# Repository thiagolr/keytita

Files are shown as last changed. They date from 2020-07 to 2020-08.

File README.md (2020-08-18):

KeyTita
========

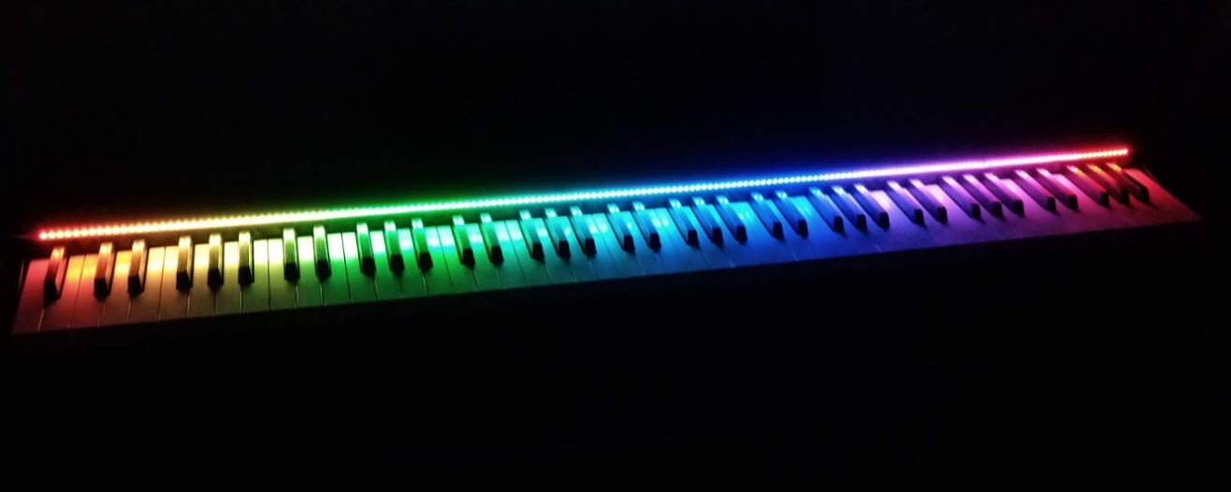
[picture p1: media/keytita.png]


This project allows you to learn a song note by note on the piano, by lighting up appropriate LED lights that correspond to each individual key on the piano.

### Modes

- <b>Learn</b>: the piano will show which note should be played and then it will wait for you
- <b>Listen</b>: the piano will play the song and you will watch which notes it is playing
- <b>Play</b>: play any song and the piano will light up the notes played

### How It Works

The main unit is composed by an Arduino Leonardo and an USB-Host Shield. The piano is connected to the USB-Host Shield and a PC or mobile device running [Synthesia](https://synthesiagame.com/) is connected to the Arduino Leonardo.

[Synthesia](https://synthesiagame.com/) shows any MIDI song as falling notes, then the Arduino Leonardo board receives this information and lights up the appropriate LED. When you press a piano key, this information is sent back to Synthesia.

An android application is available to setup the key colors and effects.

### Materials and Tools

- Arduino Leonardo
- Arduino USB-Host Board
- WS2812B Led Strip (144 led/m)
- 5V Power Supply
- 1000 uF capacitor
- 470 ohm resistor
- 3D Printer

### Electronics

A 1000 uF capacitor was added across the + and – terminals from the power supply to buffer sudden changes in the current drawn by the LED strip. A 470 ohm resistor was added to the LED strip data line to reduce the noise.

### LED Support

A [LED support](https://www.thingiverse.com/thing:4555365) was designed using OpenSCAD in order to hold the LED strip, it is fully parametric and can be easily adjusted to other pianos or keyboards.

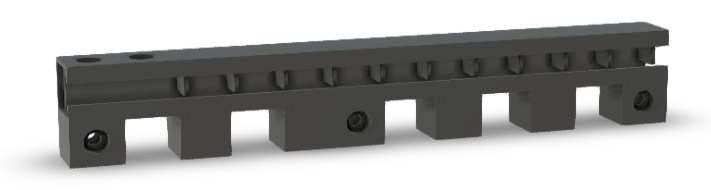
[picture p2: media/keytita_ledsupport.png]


### Box Case

The [box case](https://github.com/zygmuntw/3D-Printed-Case-for-Arduino) holding the Arduino Leonardo and the USB-Host Shield was based on the work of [Zygmunt Wojcik](https://github.com/zygmuntw). It was [modified](https://www.thingiverse.com/thing:4555365) to fit the USB-Host Shield connected above the Arduino Leonardo board.

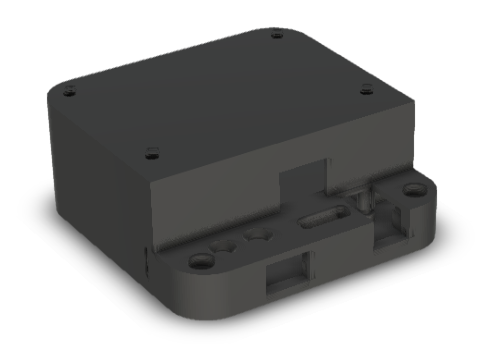
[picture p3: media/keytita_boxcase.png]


### Android Application

The application allows you to select the key colors and the brightness. There are some predefined colors and sequences/effects, but it is also possible to set custom colors.

The application is automatically launched and connected, every time you plug the USB cable between your phone/tablet and the Arduino Leonardo.

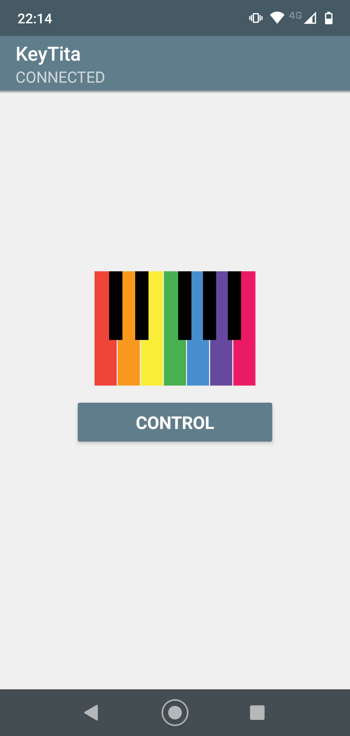
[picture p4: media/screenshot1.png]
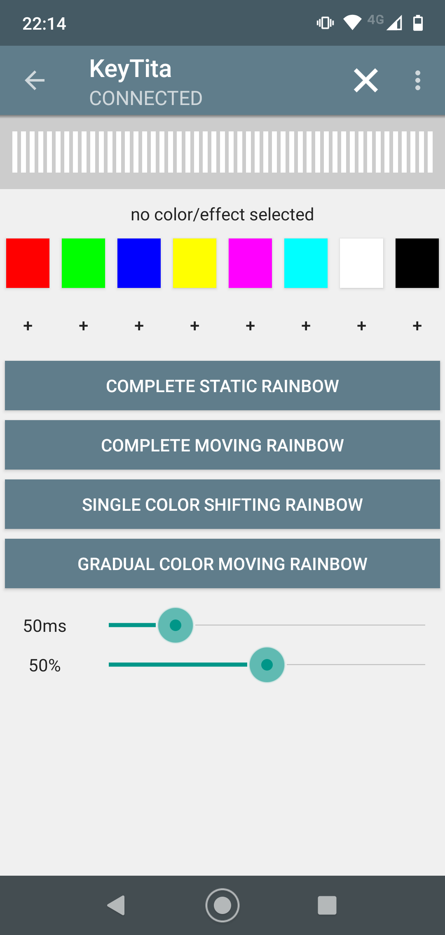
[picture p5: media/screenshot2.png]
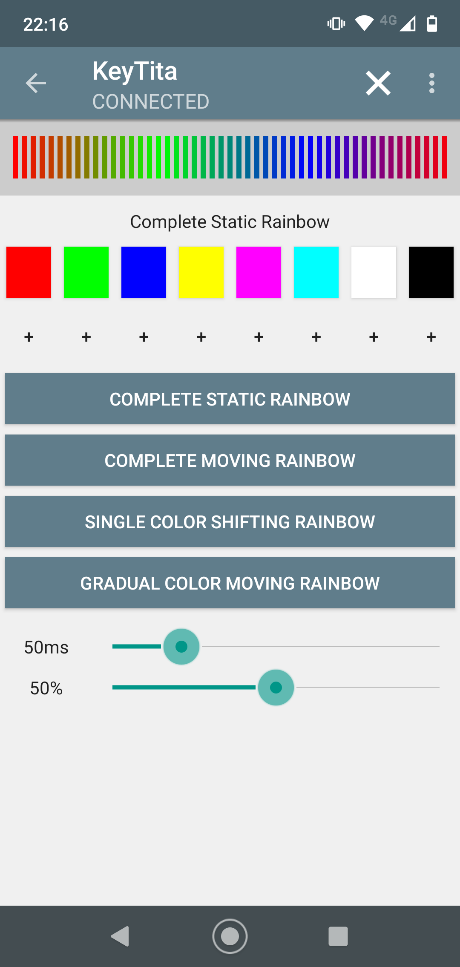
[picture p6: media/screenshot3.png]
&nbsp;&nbsp;&nbsp;&nbsp;&nbsp;&nbsp;&nbsp;&nbsp;

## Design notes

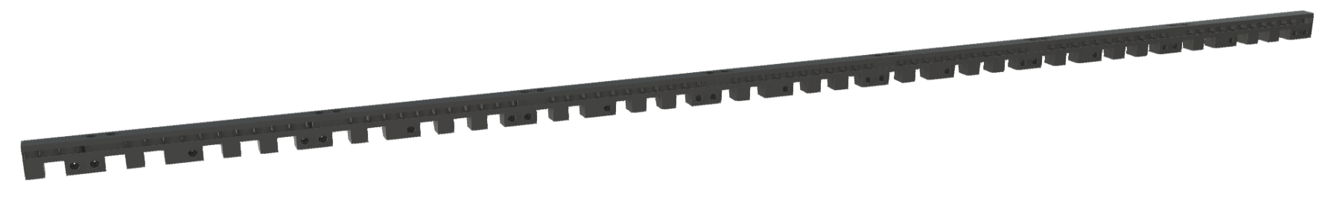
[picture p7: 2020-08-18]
media/keytita_ledsupport_full.png

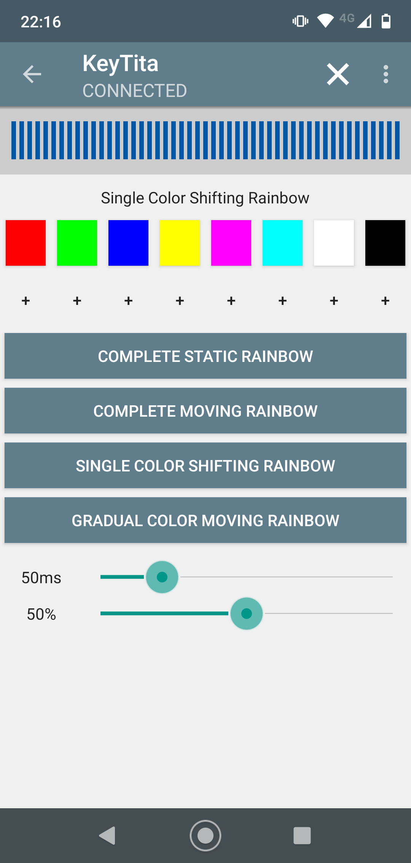
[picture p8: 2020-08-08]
media/screenshot5.png

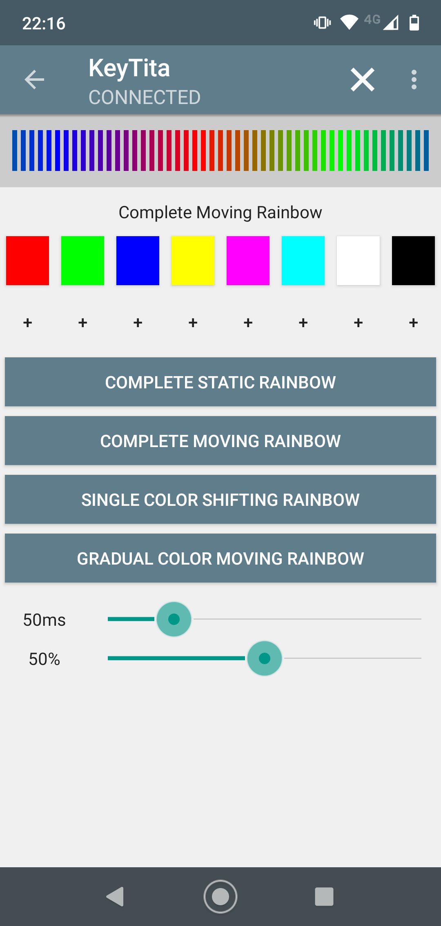
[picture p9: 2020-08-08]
media/screenshot4.png

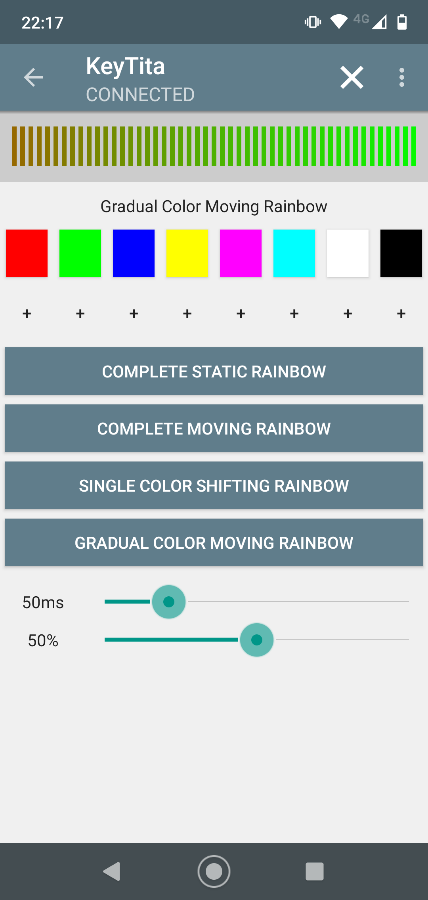
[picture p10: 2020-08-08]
media/screenshot6.png

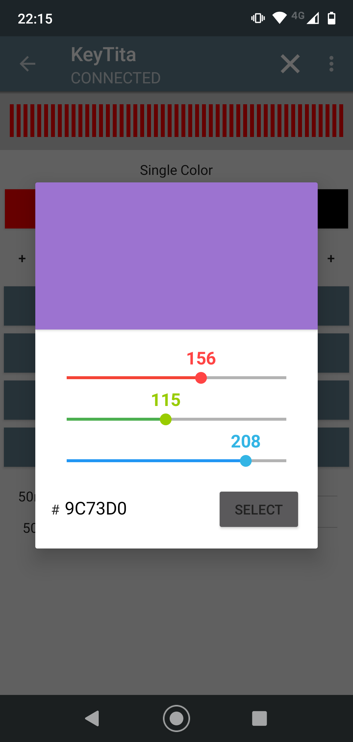
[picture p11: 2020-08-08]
media/screenshot8.png

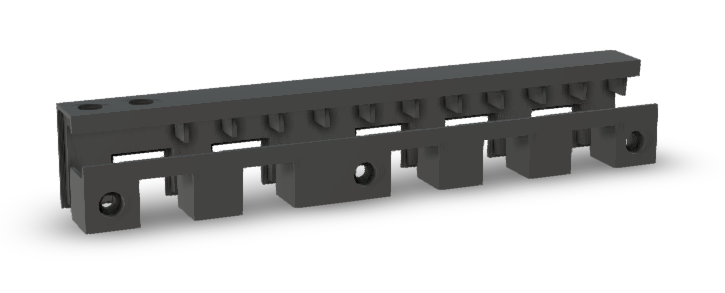
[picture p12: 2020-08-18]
media/keytita_ledsupport_exploded.png

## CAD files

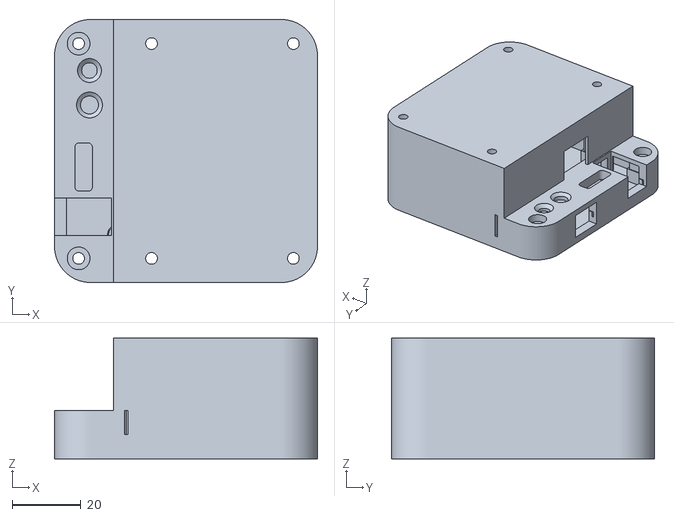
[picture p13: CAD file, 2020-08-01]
cad/KeyTita_DemoBox.stl
76.3 x 76.3 x 35.0

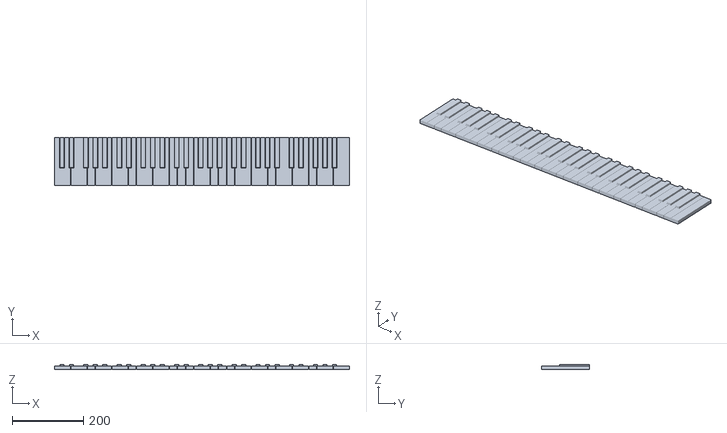
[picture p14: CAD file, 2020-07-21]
cad/Piano/Piano61.stl
827.0 x 135.0 x 15.0

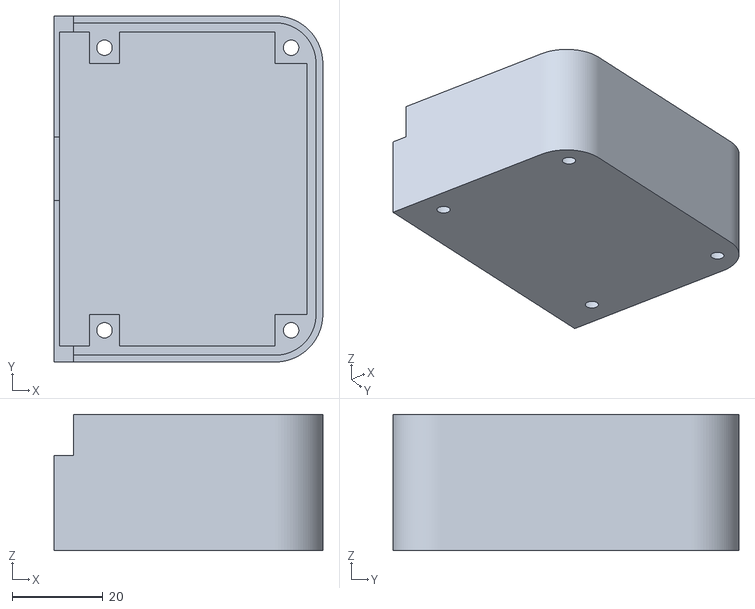
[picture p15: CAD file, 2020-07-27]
cad/KeyTita_Printer_BoxCase_LidTop.stl
59.2 x 76.3 x 30.0

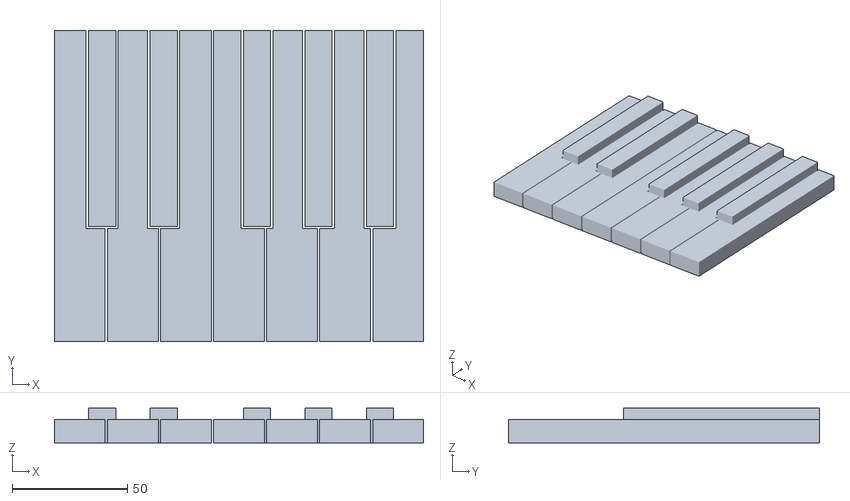
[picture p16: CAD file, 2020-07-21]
cad/Piano/Piano.stl
160.0 x 135.0 x 15.0

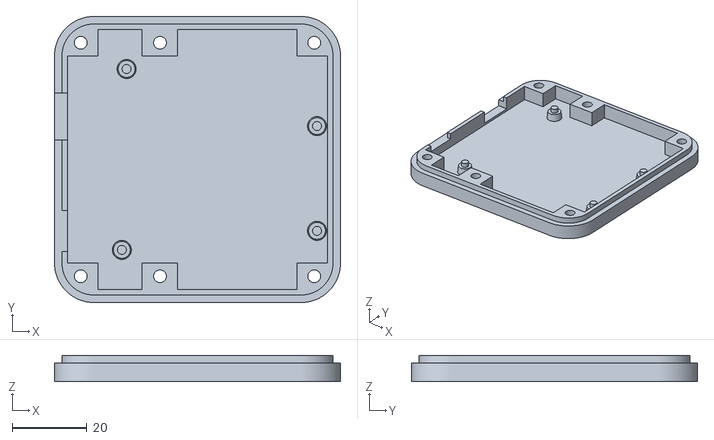
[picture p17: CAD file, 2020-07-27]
cad/KeyTita_Printer_BoxCase_Base.stl
76.3 x 76.3 x 7.00

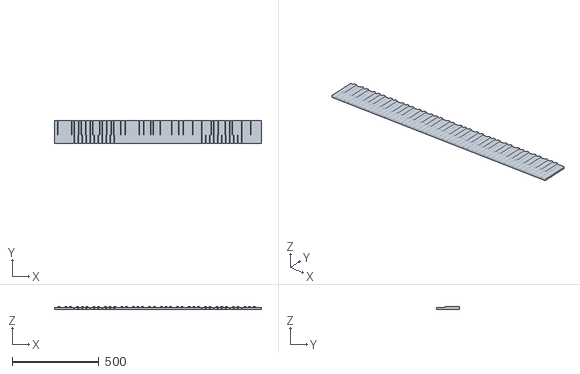
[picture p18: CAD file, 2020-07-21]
cad/Piano/Piano88.stl
1195.0 x 135.0 x 15.0

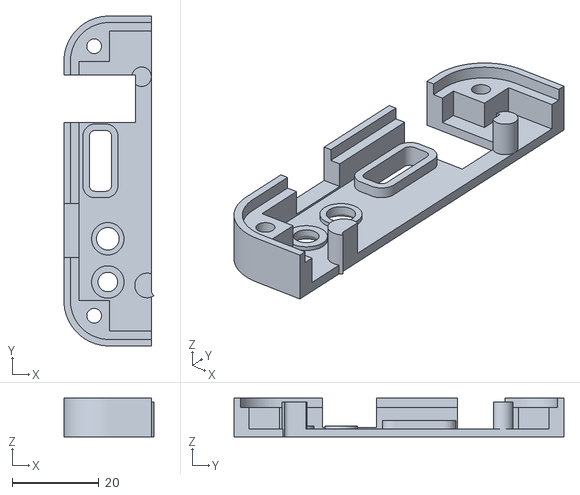
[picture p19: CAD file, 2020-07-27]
cad/KeyTita_Printer_BoxCase_LidMid.stl
20.9 x 76.3 x 9.00

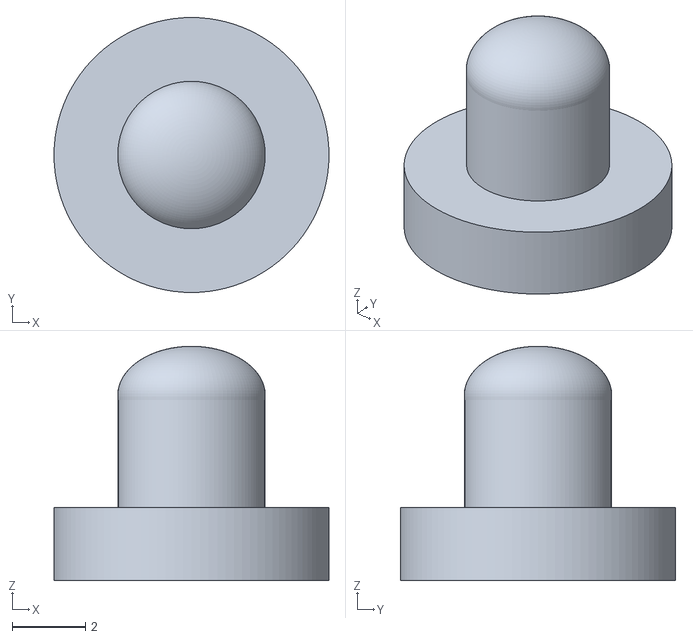
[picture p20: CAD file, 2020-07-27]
cad/KeyTita_Printer_BoxCase_Button.stl
7.50 x 7.50 x 6.39

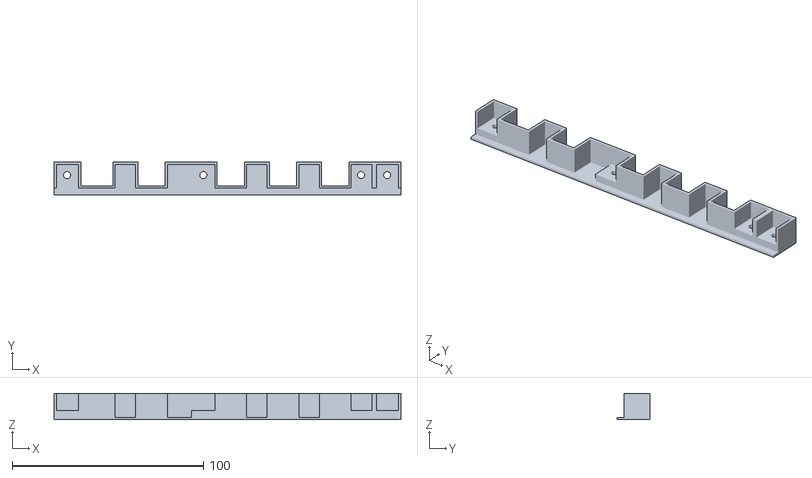
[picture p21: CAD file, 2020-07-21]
cad/KeyTita_Printer_C7C8_Front_Padded.stl
181.5 x 17.2 x 13.8

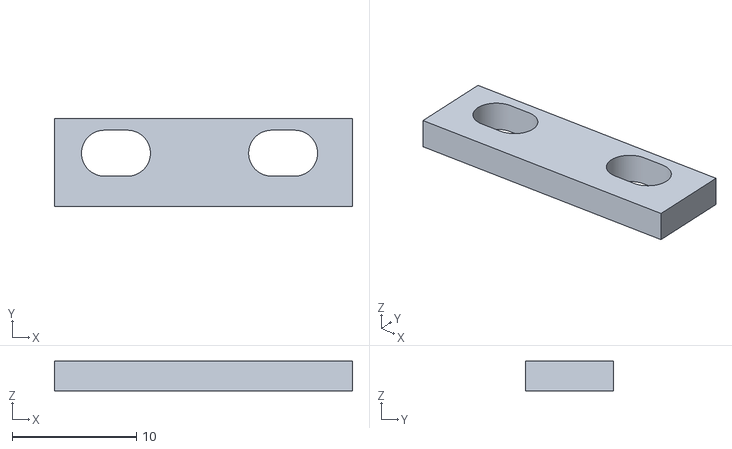
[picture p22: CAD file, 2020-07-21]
cad/KeyTita_Printer_Connector_Padded.stl
24.0 x 7.10 x 2.40

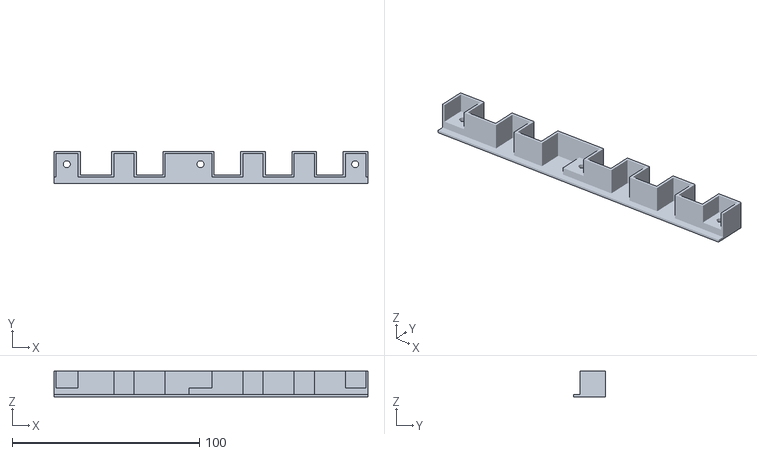
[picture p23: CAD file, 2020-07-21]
cad/KeyTita_Printer_C2C3C4C5C6_Front_Padded.stl
167.5 x 17.2 x 13.8

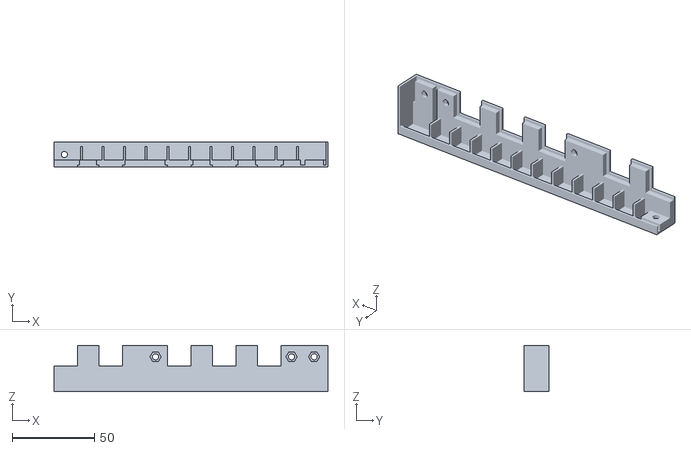
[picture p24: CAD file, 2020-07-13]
cad/KeyTita_Printer_C7C8_Back.stl
166.2 x 15.0 x 27.9

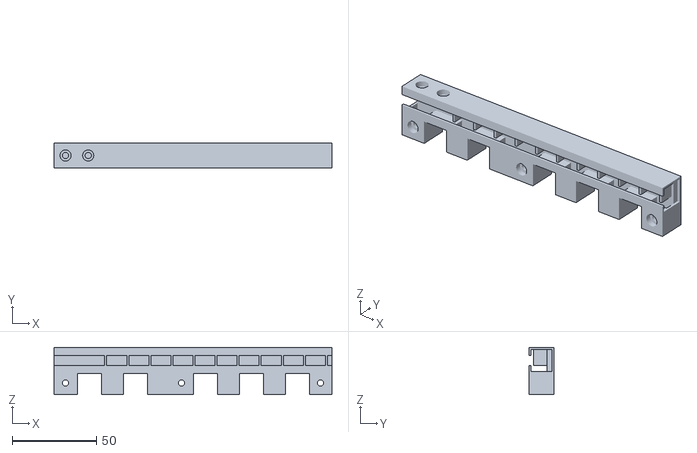
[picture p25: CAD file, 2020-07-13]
cad/KeyTita_Demo.stl
165.0 x 15.0 x 27.9

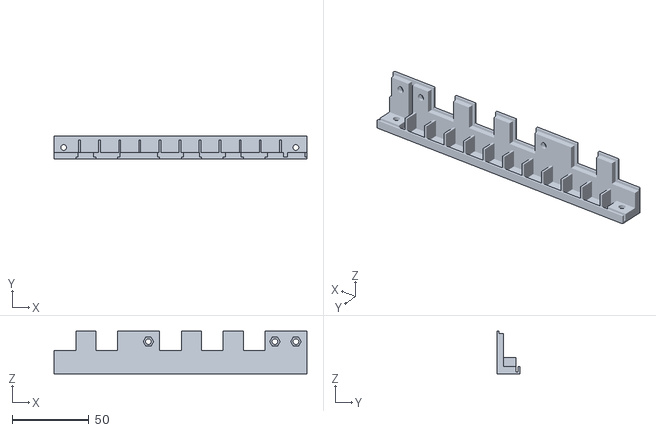
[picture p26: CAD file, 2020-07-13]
cad/KeyTita_Printer_C2C3C4C5C6_Back.stl
165.0 x 15.0 x 27.9

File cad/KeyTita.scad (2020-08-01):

/* KeyTita
 *
 * Author: Thiago Rosa (http://www.thiagorosa.com)
 * Project: KeyTita (https://github.com/thiagolr/keytita)
 * License: CC BY-SA 4.0 (https://creativecommons.org/licenses/by-sa/4.0)
 *
 */

include <Piano/Piano.scad>;

$UNIT_THICKNESS = 1.2;
$UNIT_LOCK_SIZE = 3;
$UNIT_LOCK_OFFSET = 0.2;
$UNIT_DEPTH = 15;
$UNIT_OVERLAP = 14.0625;
$UNIT_FIRST_OCTAVE = 40.59;
$UNIT_EXTRA_PADDING = 0;

$LED_SMD_SIZE = 5;
$LED_SMD_OFFSET = 0.5;
$LED_STRIP_HEIGHT = 12;
$LED_STRIP_OFFSET = 0.5;
$LED_STRIP_THICKNESS = 1.5;

$SCREW_HOLE_DIAMETER = 2.9;
$SCREW_HOLE_DIAMETER_OFFSET = 0.4;
$SCREW_HEAD_DIAMETER = 5.4;
$SCREW_HEAD_DIAMETER_OFFSET = 0.6;
$SCREW_HEAD_HEIGHT = 2.0;
$SCREW_HEAD_HEIGHT_OFFSET = 0.9;
$SCREW_HOLDER_SIZE = 11.3;
$NUT_DIAMETER = 6.0;
$NUT_DIAMETER_OFFSET = 0.4;
$NUT_HEIGHT = 2.3;
$NUT_HEIGHT_OFFSET = 0.5;

$WHITE_LENGTH = 150;
$WHITE_WIDTH = 22.5;
$WHITE_HEIGHT = 17.8;
$BLACK_LENGTH = 95;
$BLACK_HEIGHT = $WHITE_HEIGHT + 12.5;
$SPACE_WIDTH = 1.068;

$COLOR_ALPHA = 1;

// ############################################################################################

mainThickness = $UNIT_THICKNESS;
mainLockSize = $UNIT_LOCK_SIZE;
mainLockOffset = $UNIT_LOCK_OFFSET;
mainExtraPadding = $UNIT_EXTRA_PADDING;

mainBlackHeight = ($BLACK_HEIGHT - $WHITE_HEIGHT);
mainWidth = $WHITE_WIDTH * 7 + $SPACE_WIDTH * 7 + mainExtraPadding;
mainHeight = mainThickness + mainBlackHeight + $LED_STRIP_OFFSET + $LED_STRIP_HEIGHT + $LED_STRIP_OFFSET + mainThickness;
mainDepth = $UNIT_DEPTH;
mainOverlap = $UNIT_OVERLAP;
mainFirstOctave = $UNIT_FIRST_OCTAVE;

ledStripHeight = $LED_STRIP_HEIGHT + $LED_STRIP_OFFSET * 2;
ledStripPosition = mainBlackHeight + mainThickness;
ledStripThickness = $LED_STRIP_THICKNESS;
ledHolePositionBottom = ledStripPosition + ($LED_STRIP_HEIGHT - $LED_SMD_SIZE) / 2 + $LED_STRIP_OFFSET - $LED_SMD_OFFSET;
ledHolePositionTop = ledHolePositionBottom + $LED_SMD_SIZE + $LED_SMD_OFFSET * 2;
ledHoleHeight = $LED_SMD_SIZE + $LED_SMD_OFFSET * 2;
ledHolderPosition = ledHolePositionBottom;
ledHolderTransitionSupportPosition = 17;
ledHolderCount = 9;

screwHoleRadius = $SCREW_HOLE_DIAMETER / 2 + $SCREW_HOLE_DIAMETER_OFFSET;
screwHeadRadius = $SCREW_HEAD_DIAMETER / 2 + $SCREW_HEAD_DIAMETER_OFFSET;
screwHeadHeight = $SCREW_HEAD_HEIGHT + $SCREW_HEAD_HEIGHT_OFFSET;
screwHolderSize = $SCREW_HOLDER_SIZE + mainThickness;
screwHolderDepth = 3.6;
screwHolePosition = ledStripPosition / 2;
nutHoleRadius = $NUT_DIAMETER / 2 + $NUT_DIAMETER_OFFSET;
nutHoleHeight = $NUT_HEIGHT + $NUT_HEIGHT_OFFSET;

leftSideHole = true;
rightSideHole = true;
screwMargin = false;

backConnectorOffset = 0.5;

insideThickness = mainThickness + mainLockOffset;
leftMarginThickness = mainThickness + mainLockOffset * (screwMargin ? 5 : 1);

// ############################################################################################

Main(explode = true);
*Main88(explode = false);
*Box();

*PrintFront(c1 = true);
*PrintFront(c2c3c4c5c6 = true);
*PrintFront(c7c8 = true);

*PrintBack(c1 = true);
*PrintBack(c2c3c4c5c6 = true);
*PrintBack(c7c8 = true);

*PrintConnector();

// ############################################################################################

module PrintFront(c1 = false, c2c3c4c5c6 = false, c7c8 = false) {   
    if (c1) {
        rotate([90, 0, 0]) translate([-mainWidth + mainFirstOctave, 0, 0])
        difference() {
            MainFront();
            
            cube([mainWidth - mainFirstOctave, mainDepth, mainHeight]);
        }
    }
    
    if (c2c3c4c5c6) {
        rotate([90, 0, 0])
        MainFront();
    }
    
    if (c7c8) {
        rotate([90, 0, 0])
        union() {
            MainFront();
            
            difference() {
                translate([mainWidth, 0, 0])    
                    MainFront();
                
                translate([mainWidth + mainOverlap, 0, 0])
                    cube([mainWidth, mainDepth, mainHeight]);
            }
        }
    }
}

module PrintBack(c1 = false, c2c3c4c5c6 = false, c7c8 = false) {
    if (c1) {
        rotate([180, 0, 0]) translate([-mainWidth + mainFirstOctave, -mainDepth, -mainHeight])
        union() {
            difference() {
                MainBack();         
                
                cube([mainWidth - mainFirstOctave, mainDepth, mainHeight]);
            }

            difference() {
                translate([mainWidth, 0, 0])    
                    MainBack();
                
                translate([mainWidth + mainOverlap, 0, 0])
                    cube([mainWidth, mainDepth, mainHeight]);
                
                
            }
            
            color("gray")
            translate([mainWidth - mainFirstOctave, mainThickness + ledStripThickness, mainBlackHeight + mainThickness])
                cube([mainThickness, mainDepth - mainThickness - ledStripThickness, mainHeight - mainBlackHeight - mainThickness]);
        }
    }
    
    if (c2c3c4c5c6) {        
        rotate([180, 0, 0]) translate([-mainOverlap, -mainDepth, -mainHeight])
        union() {
            difference() {
                MainBack();         
                cube([mainOverlap, mainDepth, mainHeight]);        
            }

            difference() {
                translate([mainWidth, 0, 0])    
                    MainBack();
                
                translate([mainWidth + mainOverlap, 0, 0])
                    cube([mainWidth, mainDepth, mainHeight]);
            }
        }
    }
    
    if (c7c8) {
        rotate([180, 0, 0]) translate([-mainOverlap, -mainDepth, -mainHeight])
        union() {
            difference() {
                MainBack();         
                cube([mainOverlap, mainDepth, mainHeight]);        
            }

            difference() {
                translate([mainWidth, 0, 0])    
                    MainBack(topHolder = false);
                
                translate([mainWidth + mainOverlap, 0, 0])
                    cube([mainWidth, mainDepth, mainHeight]);
            }
            
            translate([mainWidth + mainOverlap, 0, 0])
                cube([mainThickness, mainDepth, mainHeight]);
        }
    }
}

module PrintConnector() {    
    translate([-leftMarginThickness - backConnectorOffset, -mainThickness - ledStripThickness - backConnectorOffset, -mainHeight + mainThickness + screwHolderDepth + mainThickness])
        BlockConnector();
}

// ############################################################################################

module Main(explode = false) {   
    if (!explode) {
        MainFront();
        MainBack();
    } else {
        translate([0, -5, 0]) MainFront();
        translate([0, 5, 0]) MainBack();
    }    
}

module Main88(explode = false) {
    space = explode ? 7 : 0.01;
    
    union() {
        translate([0, mainDepth + space, mainHeight]) rotate([-180, 0, 0]) {
            PrintBack(c1 = true);
        }

        translate([mainOverlap, mainDepth + space, mainHeight]) rotate([-180, 0, 0]) {
            translate([mainFirstOctave, 0, 0]) PrintBack(c2c3c4c5c6 = true);
            translate([mainFirstOctave + mainWidth, 0, 0]) PrintBack(c2c3c4c5c6 = true);
            translate([mainFirstOctave + mainWidth * 2, 0, 0]) PrintBack(c2c3c4c5c6 = true);
            translate([mainFirstOctave + mainWidth * 3, 0, 0]) PrintBack(c2c3c4c5c6 = true);
            translate([mainFirstOctave + mainWidth * 4, 0, 0]) PrintBack(c2c3c4c5c6 = true);
            translate([mainFirstOctave + mainWidth * 5, 0, 0]) PrintBack(c2c3c4c5c6 = true);
            translate([mainFirstOctave + mainWidth * 6, 0, 0]) PrintBack(c7c8 = true);
        }    
        
        translate([0, -space, 0]) rotate([-90, 0, 0]) {
            PrintFront(c1 = true);
            translate([mainFirstOctave, 0, 0]) PrintFront(c2c3c4c5c6 = true);
            translate([mainFirstOctave + mainWidth, 0, 0]) PrintFront(c2c3c4c5c6 = true);
            translate([mainFirstOctave + mainWidth * 2, 0, 0]) PrintFront(c2c3c4c5c6 = true);
            translate([mainFirstOctave + mainWidth * 3, 0, 0]) PrintFront(c2c3c4c5c6 = true);
            translate([mainFirstOctave + mainWidth * 4, 0, 0]) PrintFront(c2c3c4c5c6 = true);
            translate([mainFirstOctave + mainWidth * 5, 0, 0]) PrintFront(c2c3c4c5c6 = true);
            translate([mainFirstOctave + mainWidth * 6, 0, 0]) PrintFront(c7c8 = true);
        }    
    }    
}

module MainFront() {
    difference() {
        BlockMainFront();                
        BlockScrew();
    }
}

module MainBack(topHolder = true) {
    difference() {
        BlockMainBack(topHolder = topHolder);
        BlockNut();
        BlockScrew(back = true, topHolder = topHolder);
    }
}
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

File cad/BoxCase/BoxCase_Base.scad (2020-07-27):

//  ----------------------------------------------------------------------- LICENSE
//  This "3D Printed Case for Arduino Uno, Leonardo" by Zygmunt Wojcik is licensed
//  under the Creative Commons Attribution-ShareAlike 3.0 Unported License.
//  To view a copy of this license, visit
//  http://creativecommons.org/licenses/by-sa/3.0/
//  or send a letter to Creative Commons, PO Box 1866, Mountain View, CA 94042, USA.


include <BoxCase_Params.scad>

$NUT_DIAMETER = 6.0;
$NUT_DIAMETER_OFFSET = 0.8;
$NUT_HEIGHT = 2.3;
$NUT_HEIGHT_OFFSET = 0.6;

nutHoleRadius = $NUT_DIAMETER / 2 + $NUT_DIAMETER_OFFSET;
nutHoleHeight = $NUT_HEIGHT + $NUT_HEIGHT_OFFSET;

module NutHole() {
    color("orangeRed")
    
    rotate([90, 0, 0])
        translate([0, 0, -nutHoleHeight / 2]) 
            cylinder(r = nutHoleRadius, h = nutHoleHeight, center = true, $fn = 6);   
}

//------------------------------------------------------------------------- MODULES
module pcbLeg() {		
	translate([0, 0, 0])
	difference() { 											
		cylinder(h = floorHeight + pcbPositionZ, r1=5.5/2, r2 = 4.5/2);
	}
}


//------------------------------------------------------------------------- MAIN BLOCK
difference()
{
																		// ADD
	union()
	{
		// Add Base
		linear_extrude(height = height/2, convexity = 10)
		minkowski()
		{									
			square([width, wide], center = true);
			circle(roundR);
		}
	}
																		// SUBSTRACT
	union()
	{
		// Lift floor height
		translate([0, 0, floorHeight])
		{
			// Cut Base hole
			linear_extrude(height = height/2, convexity = 10)
			minkowski()
			{
				square([width, wide], center = true);
				circle(roundR - pillarSize);
			}
			// Cut upper block lock
			difference() {
				translate([0, 0, height/2 - floorHeight - blockLockSize]) {
					cylinder(h = blockLockSize+gap, r=width);
				}
				translate([0, 0, height/2 - floorHeight - blockLockSize - gap*2]) {
					linear_extrude(height = blockLockSize+gap*4, convexity = 10)
					minkowski() {
						square([width, wide], center=true);
						circle(roundR - layerWidth*4);
					}
				}
			}
			// Cut x panels 
			for (i = [0 : 180 : 180])				
			rotate([0, 0, i])
			translate([width/2 + roundR - pillarSize/2 - layerWidth*7, 0, 0])
			{
				// Cut X panel hole
				translate([0, 0, height/2])
				cube([pillarSize, sidePanelXWidth, height], center=true);
                
				// Cut X, Y srew holes
				for (j = [wide/2, -wide/2])
				{
					translate([-(roundR - pillarSize/2 - layerWidth*7), j, - floorHeight])
					if (j>0) 
					{
						rotate([0, 0, 45])
						translate([screwHoleRoundR, 0, 0])
						{
							cylinder(h = height*2, r=screwExt/2, center=true);
							cylinder(h = 5,
                                    r1 = (screwHead + (screwHead - screwExt))/2,
                                    r2 = screwExt/2, center=true);
                            rotate([90, 0, 135]) NutHole();
						}
					}
					else
					{
						rotate([0, 0, -45])
						translate([screwHoleRoundR, 0, 0])
						{
							cylinder(h = height*2, r=screwExt/2, center=true);
							cylinder(h = 5,
                                    r1 = (screwHead + (screwHead - screwExt))/2,
                                    r2 = screwExt/2, center=true);
                            rotate([90, 0, -135]) NutHole();
						}
                        
             color("blue") rotate([0, 0, 90])  translate([-3.5,-j+(i == 0 ? 10 : -10),0])  {
              cylinder(h = height*2, r=screwExt/2, center=true);
							cylinder(h = 5,
                                    r1 = (screwHead + (screwHead - screwExt))/2,
                                    r2 = screwExt/2, center=true);
                            rotate([90, 0, -150]) NutHole();  
			}
                        
					}
				}
			}
			// Cut Y panels 
			for (i = [90 : 180 : 270])
			rotate([0, 0, i])
			translate([wide/2 + roundR - pillarSize/2 - layerWidth*7, 0, 0])
			{
				// Cut Y panel hole
				*translate([0, 0, height/2])
				cube([pillarSize, sidePanelYWidth, height], center=true);
                
                // Cut Y panel hole
				translate([0, i == 90 ? -10.6 : 10.6, height/2])
				cube([pillarSize, sidePanelYWidth-23.4, height], center=true);
                
                translate([0, (i == 90 ? 18.5 + 2.2 : -18.5 - 2.2), height/2])
				cube([pillarSize, 14-2.2, height], center=true);
			}
			
            // Cut USB and Power holes
			// translate to pcb position
			translate([-pcbPositionX, -pcbWide/2, pcbPositionZ + pcbHeight])
			{
				// cut power hole
				translate([0, powerJackPosition, (powerJackHeight-2)/2])
				cube([10, powerJackWide, powerJackHeight], center=true);
				// cut usb hole
				translate([0, usbHolePosition, 1.3])
				cube([10, usbWide, usbHeight], center=true);
			}
		}
	}
}
//------------------------------------------------------------------------- ADD PCB LEGS
// Translate to pcbPositionX	
translate([-pcbPositionX, -pcbWide/2, 0])

difference()
{
																		// ADD
	union()
	{
		// Add pcb legs
		for(i=[ [13.97, 2.54, 0], 				
     	    	[15.24, 50.8, 0],
          		[66.04, 35.56, 0],
          		[66.04, 7.62, 0] ])
		{
	    		translate(i)
	    		pcbLeg();
		}
		// Add pcb holders
		for(i=[ [13.97, 2.54, 0],
     	    	[15.24, 50.8, 0],
          		[66.04, 35.56, 0],
     	    	[66.04, 7.62, 0] ])
		{
			translate(i)
			cylinder(h=floorHeight+pcbPositionZ+1.5, r=1.2);
		}
	}
																		// SUBSTRACT
	union()
	{
		//
	}
}

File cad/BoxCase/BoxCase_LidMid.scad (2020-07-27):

//  ----------------------------------------------------------------------- LICENSE
//  This "3D Printed Case for Arduino Uno, Leonardo" by Zygmunt Wojcik is licensed
//  under the Creative Commons Attribution-ShareAlike 3.0 Unported License.
//  To view a copy of this license, visit
//  http://creativecommons.org/licenses/by-sa/3.0/
//  or send a letter to Creative Commons, PO Box 1866, Mountain View, CA 94042, USA.


include <BoxCase_Params.scad>



frontX = 100;//100;
frontY = 20;//20;
height = 14;//14

backX = 0;
//height = 56;//14

*color("blue") cube([10,10,9]);
*translate([0,0,21]) color("blue") cube([10,10,9]);
*translate([-33,20,21-8]) color("cyan") cube([3,3,17]);
*color("magenta",0.5) cube([5,5,30]);

/*difference() {
color("green", 0.3) translate([-20.5,0,21/2]) cube([1.2,width+ 2 * roundR,21], center = true);

color("yellow", 1) translate([-20.5, 4.45,21]) cube([2.54 + 1.27*2,11.5 + 1.27*2,24], center = true);
}*/



//------------------------------------------------------------------------- PARAMETERS
// lid holes dimensions
connectorRoundR = 2.54/2;
connectorWide = 2.54*3;

upperConnectorWidth = 44.704 + 2.54*2;
upperConnectorXPos = 18.796 - 2.54;
upperConnectorYPos = 50.8 - 2.54*2;
lowerConnectorWidth = 35.56 + 2.54*2;
lowerConnectorXPos = 27.94 - 2.54;
lowerConnectorYPos = 2.54 - 2.54;

icspConnectorWidth = 5.08 + 2.54*2;
icspConnectorWide = 2.54 + 2.54*2;
icspConnectorXPos = 63.64 - 2.54;
icspConnectorYPos = 30.43 + 2.54;

ledHoleWidth = 2.54 + 1.27*2;
ledHoleWide = 11.5 + 1.27*2;
ledHoleXPos = 4.45;
ledHoleYPos = 22 ;

buttonSize = 4;
buttonXPos = 6.15;
buttonYPos = 50;
buttonBaseHeight = 2;
buttonBaseR = buttonSize/2 + 0.25 + layerWidth*3;

$SCREW_HEAD_DIAMETER = 5.4;
$SCREW_HEAD_DIAMETER_OFFSET = 0.6;
$SCREW_HEAD_HEIGHT = 2.0;
$SCREW_HEAD_HEIGHT_OFFSET = 0.9;

screwHeadRadius = $SCREW_HEAD_DIAMETER / 2 + $SCREW_HEAD_DIAMETER_OFFSET;
screwHeadHeight = $SCREW_HEAD_HEIGHT + $SCREW_HEAD_HEIGHT_OFFSET;
 

//------------------------------------------------------------------------- MODULES
module pcbLeg() {		
	translate([0, 0, 0])
	difference() { 											
		cylinder(h = height - floorHeight - pcbPositionZ - pcbHeight, r = 5.7/2);
	}
}

module buttonFrame() {
	translate([0, 0, -0.05])
	cylinder(h=1.5, r1=buttonSize/2 + 0.5 + 1, r2=buttonSize/2 + 0.2);
}

module buttonFrame2() {
	translate([0, 0, -0.05])
	cylinder(h=1.5, r1=buttonSize/2 + 0.8 + 1, r2=buttonSize/2 + 0.2);
}


//------------------------------------------------------------------------- MAIN BLOCK
difference()
{
																		// ADD
	union()
	{
		// Add Base
		linear_extrude(height = height/2 + blockLockSize, convexity = 10)
		minkowski()
		{									
			square([width, wide], center = true);
			circle(roundR);
		}
	}
																		// SUBSTRACT
	union()
	{
		// lift floor height
		translate([0, 0, floorHeight])
		{
			// Cut base inner hole
			linear_extrude(height = height, convexity = 10)
			minkowski()
			{
				square([width, wide], center = true);
				circle(roundR - pillarSize);
			}
			// Cut block lock
			translate([0, 0, height/2 - blockLockSize])
			linear_extrude(height = height, convexity = 10)
			minkowski()
			{
				square([width, wide], center = true);
				circle(roundR - layerWidth*3);
			}
			// Cut x panels 
			for (i = [0 : 180 : 180])				
			rotate([0, 0, i])
			translate([width/2 + roundR - pillarSize/2 - layerWidth*7, 0, 0])
			{
                // Cut X panel hole
				translate([0, 0, height/2])
				cube([pillarSize, sidePanelXWidth, height], center=true);

				// Cut X, Y srew holes
				for (j = [wide/2, -wide/2])
				{ 
                  
					translate([-(roundR - pillarSize/2 - layerWidth*7), j,
                    -(floorHeight-layerHeight*3 + height)]) {
					if (j>0) 
					{
						rotate([0, 0, 45])
						translate([screwHoleRoundR, 0, 0]) {
						cylinder(h=height * 2, r=screwExt/2);
                        translate([0, 0, -layerHeight*3 + height]) cylinder(r = screwHeadRadius, h = screwHeadHeight + 10.2, center = false, $fn = 100); 
                        }
					}
					else
					{
						rotate([0, 0, -45])
						translate([screwHoleRoundR, 0, 0]) {
						cylinder(h=height * 2, r=screwExt/2);
                        translate([0, 0, -layerHeight*3 + height]) cylinder(r = screwHeadRadius, h = screwHeadHeight+ 10.2, center = false, $fn = 100);                        
                        
                        
                        
                        }
                                             
        color("blue") rotate([0, 0, 90])  translate([-3.5,-j+(i == 0 ? 10 : -10),0])  {
                cylinder(h=height * 2, r=screwExt/2);
                        translate([0, 0, -layerHeight*3 + height]) cylinder(r = screwHeadRadius, h = screwHeadHeight + 10.2, center = false, $fn = 100); 
  
			}
            
                  
       
        
        }
                         
                        
                         
					}  
                
                     
                    
				}
                
                         
            

            }
            
            // Cut Y panels 
			for (i = [90 : 180 : 270])
			rotate([0, 0, i])
			translate([wide/2 + roundR - pillarSize/2 - layerWidth*7, 0, 0])
			{
              // Cut Y panel hole
				translate([0, backX > 0 ? (i == 90 ? -10.5 : 10.5) : (i == 90 ? -1 : 1), height/2])
				cube([pillarSize, sidePanelYWidth+(backX > 0 ? -21 : 0), height], center=true);
                
                if (backX > 0) translate([0, i == 90 ? 41 : -41, height/2])
				cube([pillarSize, sidePanelYWidth, height], center=true);
			}
            
            // Cut USB and Power holes
			// Rotate due to panel upside down
			mirror([0, 1 , 0])
            
			// translate to pcb position
			translate([-pcbPositionX, -pcbWide/2, height - floorHeight*2 -pcbPositionZ-pcbHeight])
			{
				// Cut power hole
				translate([0, powerJackPosition, -(powerJackHeight-2)/2])
				cube([25, powerJackWide, powerJackHeight], center=true);
				// Cut usb hole
				translate([0, usbHolePosition, -1.3])
				cube([10, usbWide, usbHeight], center=true);
                
				// Cut connectors holes
				// upper
                // thiago
                if (backX == 0)
				translate([upperConnectorXPos + upperConnectorWidth/2 + frontY / 2,
						upperConnectorYPos + connectorWide/2 - upperConnectorYPos / 2,
						-25])
				linear_extrude(height = 50, convexity = 10)
				minkowski()
				{									
					square([upperConnectorWidth - connectorRoundR*2 + frontY,
					connectorWide - connectorRoundR*2 + upperConnectorYPos + frontX], center = true);
					circle(connectorRoundR);
				}
				// lower
				*translate([lowerConnectorXPos + lowerConnectorWidth/2,
						lowerConnectorYPos + connectorWide/2,
						-25])
				linear_extrude(height = 50, convexity = 10)
				minkowski()
				{									
					square([lowerConnectorWidth - connectorRoundR*2,
					connectorWide - connectorRoundR*2], center = true);
					circle(connectorRoundR);
				}
				// icsp
                if (backX == 0)
				translate([icspConnectorXPos + icspConnectorWide/2,
						icspConnectorYPos - icspConnectorWidth/2,
						-25])
				linear_extrude(height = 50, convexity = 10)
				minkowski()
				{									
					square([icspConnectorWide - connectorRoundR*2,
					icspConnectorWidth - connectorRoundR*2], center = true);
					circle(connectorRoundR);
				}
				// led hole
				translate([ledHoleXPos ,
						ledHoleYPos ,
						-25])
				linear_extrude(height = 50, convexity = 10)
				minkowski()
				{									
					square([ledHoleWidth - connectorRoundR*2,
					ledHoleWide - connectorRoundR*2], center = true);
					circle(connectorRoundR);
				}
				// button
				translate([buttonXPos, buttonYPos, -25])
				cylinder(h = 50, r = buttonSize/2 + 0.5);
				// buttonFrame
				translate([buttonXPos, buttonYPos, -(height - floorHeight -pcbPositionZ-pcbHeight)])
				buttonFrame();
                
                // wires
                translate([buttonXPos, buttonYPos - 10, -25])
				cylinder(h = 50, r = buttonSize/2 + 0.8);
				// buttonFrame
				translate([buttonXPos, buttonYPos - 10, -(height - floorHeight -pcbPositionZ-pcbHeight)])
				buttonFrame2();
			}
		}
	}
    
    if (backX > 0) rotate([0,180,0]) {
    translate([20,-backX/2,-backX/2]) cube([backX,backX,backX]);
    translate([20-3.2,-backX/2,-backX-21]) cube([backX,backX,backX]);        
    }
}


//------------------------------------------------------------------------- ADD PCB LEGS
// Rotate due to panel upside down
mirror([0, 1 , 0])

// Translate to pcbPositionX	
translate([-pcbPositionX, -pcbWide/2, 0])
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

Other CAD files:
cad/KeyTita_Printer_Connector.stl
cad/KeyTita_Printer_C0_Front.stl
cad/KeyTita_Printer_C2C3C4C5C6_Front.stl
cad/KeyTita_Printer_C0_Back.stl
cad/BoxCase/BoxCase_LidTop.scad
cad/BoxCase/BoxCase_Button.scad
cad/BoxCase/BoxCase_Params.scad
cad/KeyTita_Demo_Exploded.stl
cad/KeyTita_Printer_C7C8_Front.stl
cad/Piano/Piano.scad

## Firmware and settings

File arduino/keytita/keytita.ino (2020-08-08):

/*
  Copyright (c) 2020 Thiago Lopes Rosa

 Licensed under the Apache License, Version 2.0 (the "License");
 you may not use this file except in compliance with the License.
 You may obtain a copy of the License at

 http://www.apache.org/licenses/LICENSE-2.0

 Unless required by applicable law or agreed to in writing, software
 distributed under the License is distributed on an "AS IS" BASIS,
 WITHOUT WARRANTIES OR CONDITIONS OF ANY KIND, either express or implied.
 See the License for the specific language governing permissions and
 limitations under the License.
 */
 
#include <FastLED.h>
#include <SPI.h>
#include <USB-MIDI.h>

#include <usbh_midi.h>
#include <usbhub.h>

//#define DEBUG

#ifdef DEBUG
    #define PRINT(x) Serial.print(x)
    #define PRINTLN(x) Serial.println(x)
    #define PRINTNOTE(x, y, z, w) printNote(x, y, z, w)
    #ifdef VERBOSE    
        #define PRINTNOTE_VERBOSE(x, y, z, w) printNote(x, y, z, w)
    #else
        #define PRINTNOTE_VERBOSE(x, y, z, w)
    #endif 
#else
    #define PRINT(x)
    #define PRINTLN(x)
    #define PRINTNOTE(x, y, z, w)
    #define PRINTNOTE_VERBOSE(x, y, z, w)
#endif

// ###################################################################################################################################
// ###################################################################################################################################

#define TYPE_CLEAR 0
#define TYPE_COLOR 1
#define TYPE_SPEED 2
#define TYPE_BRIGHTNESS 3
#define TYPE_DEMO 4

#define TYPE_RANDOM_COLOR 11
#define TYPE_RAINBOW_FULL_FIXED 12
#define TYPE_RAINBOW_FULL_MOVING 13
#define TYPE_RAINBOW_SINGLE_SHIFTING 14
#define TYPE_RAINBOW_GRADUAL_MOVING 15

#define DEFAULT_BRIGHTNESS 10
#define DEFAULT_SPEED 100

char btData[20];
byte btIndex = 0;

bool btDemo = false;
byte btType = 0;
int btVelocity = DEFAULT_SPEED;
byte btColorRed = 0;
byte btColorGreen = 0;
byte btColorBlue = 0;
int movingIndex = 0;

// ###################################################################################################################################
// ###################################################################################################################################

#define PIN_LED 2
#define NUM_LEDS 172
#define NUM_KEYS 88

const byte mapping[NUM_KEYS] = { 0,2,4,6,8,10,12,14,16,18,20,22,24,26,28,30,32,34,36,38,40,42,44,46,47,49,51,53,55,57,59,61,63,65,67,69,71,73,75,77,79,81,83,85,87,89,91,93,94,96,98,100,102,104,106,108,110,112,114,116,118,120,122,124,126,128,130,132,134,136,138,140,142,144,146,148,150,152,154,156,158,160,162,164,166,168,169,171 };
byte channels[NUM_KEYS];

CRGB leds[NUM_LEDS];

// ###################################################################################################################################
// ###################################################################################################################################

#define MIDI_THRU_CHANNEL 15
#define MIDI_LIGHT_CHANNEL 16

USB Usb;
USBMIDI_CREATE_DEFAULT_INSTANCE();

USBH_MIDI MIDI_Piano(&Usb);
#define MIDI_Synthesia MIDI

// ###################################################################################################################################
// ###################################################################################################################################

void setup() {       
    pinMode(LED_BUILTIN, OUTPUT);

    Serial.begin(115200);
    //while (!Serial) {
    //    digitalWrite(LED_BUILTIN, HIGH); 
    //    delay(500);
    //    digitalWrite(LED_BUILTIN, LOW); 
    //    delay(500);
    //}

    PRINTLN("LED");
    FastLED.addLeds<WS2812B, PIN_LED, GRB>(leds, NUM_LEDS);
    FastLED.setBrightness(DEFAULT_BRIGHTNESS);
    FastLED.show();

    PRINTLN("MIDI");
    MIDI_Synthesia.setHandleNoteOn(handleSynthesiaNoteOn);
    MIDI_Synthesia.setHandleNoteOff(handleSynthesiaNoteOff);
    MIDI_Synthesia.begin(MIDI_CHANNEL_OMNI);
    
    PRINTLN("USB");
    while (Usb.Init() == -1) {
        digitalWrite(LED_BUILTIN, HIGH); 
        delay(1000);
        digitalWrite(LED_BUILTIN, LOW);
        delay(500);
    }
    
    delay(200);
    digitalWrite(LED_BUILTIN, HIGH); 

    for (int i = 0; i < NUM_KEYS; i++) {
        channels[i] = 0;
    }

    btType = TYPE_DEMO;
    btDemo = true;

    PRINTLN("READY");
}

void loop() {
    MIDI_Synthesia.read();
    Usb.Task();
    
    if (Usb.getUsbTaskState() == USB_STATE_RUNNING) {
        handleUsb();
    }
    
    while (Serial.available() > 0) {
        char data = Serial.read();

        btData[btIndex] = data;
        btIndex++;
    }

    if (btIndex > 0 && btData[btIndex - 1] == '#') {
        btData[btIndex - 1] = '\0';
        btIndex = 0;
      
        char * data;
        data = strtok(btData, ",");
        int type = atoi(data);

        PRINTLN(type);

        switch (type) {
            case TYPE_CLEAR:
                btType = type;
                break;   
            case TYPE_COLOR:        
                btType = type;
                data = strtok(NULL, ",");
                btColorRed = atoi(data);
                data = strtok(NULL, ",");
                btColorGreen = atoi(data);
                data = strtok(NULL, ",");
                btColorBlue = atoi(data);
                break;     
            case TYPE_SPEED:     
                data = strtok(NULL, ",");
                btVelocity = atoi(data);    
                break;            
            case TYPE_BRIGHTNESS:
                data = strtok(NULL, ",");
                FastLED.setBrightness(atoi(data));
                break;
            default:
                btType = type;
                movingIndex = 0;
                break;          
        }

        btDemo = true;  
    }

    if (btDemo) {
        handleLedDemo();
    }
}

// ###################################################################################################################################
// ###################################################################################################################################

void handleLedDemo() {  
    if (btType == TYPE_CLEAR) {
        btDemo = false;
    }
    
    for (int i = 0; i < NUM_LEDS; i++) {
        leds[i] = getLed(i);
    }

    FastLED.show();

    movingIndex++;
    delay(btVelocity);
}

void handleUsb() {
    uint8_t buffer[3];
    uint8_t size = 0;
  
    do {
        buffer[0] = 0;
        buffer[1] = 0;
        buffer[2] = 0;
    
        size = MIDI_Piano.RecvData(buffer);
        
        if (size > 0) {          
            if (buffer[0] >= 128 && buffer[0] <= 143) {
                handlePianoNoteOff(buffer[0] - 127, buffer[1], buffer[2]);
            } else if (buffer[0] >= 144 && buffer[0] <= 159) {
                handlePianoNoteOn(buffer[0] - 143, buffer[1], buffer[2]);             
            } else if (buffer[0] >= 176 && buffer[0] <= 191) {
                // control change
            } else if (buffer[0] >= 224 && buffer[0] <= 239) {
                // pitch wheel
            } else if (buffer[0] == 254) {
                // active sensing
            } else {
                PRINT("Unhandled status byte: ");
                PRINT(buffer[0]);
            }  
        }
    } while (size > 0);
}

void handleSynthesiaNoteOn(byte channel, byte note, byte velocity) {    
    if (channel == MIDI_THRU_CHANNEL) {
        return;      
    }
  
    PRINTNOTE("RCV SYN ON ", channel, note, velocity);

    if (channel == MIDI_LIGHT_CHANNEL) {       
        handleLed(true, channel, note);    
    } else {
        uint8_t buffer[3];
        buffer[0] = channel + 143;
        buffer[1] = note;
        buffer[2] = velocity;
        MIDI_Piano.SendData(buffer);
        
        PRINTNOTE_VERBOSE("SND PIA ON ", buffer[0] - 143, buffer[1], buffer[2]);
    }
}

void handleSynthesiaNoteOff(byte channel, byte note, byte velocity) {
    if (channel == MIDI_THRU_CHANNEL) {
        return;      
    }

    PRINTNOTE("RCV SYN OFF", channel, note, velocity);

    if (channel == MIDI_LIGHT_CHANNEL) {
        handleLed(false, channel, note);
    } else {
        uint8_t buffer[3];
        buffer[0] = channel + 127;
        buffer[1] = note;
        buffer[2] = 0;
        MIDI_Piano.SendData(buffer);

        PRINTNOTE_VERBOSE("SND PIA OFF", buffer[0] - 127, buffer[1], buffer[2]);
    }
}

void handlePianoNoteOn(byte channel, byte note, byte velocity) {
    handleLed(true, channel, note);  
    
    PRINTNOTE_VERBOSE("RCV PIA ON ", channel, note, velocity);                    
    PRINTNOTE("SND SYN ON ", MIDI_THRU_CHANNEL, note, velocity);     
    MIDI_Synthesia.sendNoteOn(note, velocity, MIDI_THRU_CHANNEL);
}

void handlePianoNoteOff(byte channel, byte note, byte velocity) {
    handleLed(false, channel, note);

    PRINTNOTE_VERBOSE("RCV PIA OFF", channel, note, 0);
    PRINTNOTE("SND SYN OFF", MIDI_THRU_CHANNEL, note, 0);
    MIDI_Synthesia.sendNoteOff(note, 0, MIDI_THRU_CHANNEL);
}

void handleLed(bool enable, byte channel, byte note) {
    if (btDemo) {
        btDemo = false;
        disableLeds();
    } 

    if (enable) {
        PRINTNOTE_VERBOSE("SND LED ON ", channel, note, 0);
    } else {
        PRINTNOTE_VERBOSE("SND LED OFF", channel, note, 0);
    }

    byte index = note - 21;
    byte led = mapping[index];
    if (enable) {
        if (channels[index] != MIDI_LIGHT_CHANNEL) {
            channels[index] = channel;
            leds[led] = getLed(led);
        }
    } else {
        if (channels[index] == channel) {
            channels[index] = 0;    
            leds[led] = CRGB::Black;      
        }
    }
    FastLED.show();
}

CRGB getLed(byte pos) {
    switch (btType) {
        case TYPE_CLEAR:
            return CRGB::Black;
        case TYPE_COLOR:
            return CRGB(btColorRed, btColorGreen, btColorBlue);  
        case TYPE_DEMO:
            if (btDemo) {
                return rainbowCompleteMoving(pos);    
            } else {
                return rainbowCompleteStatic(pos);
            }
        case TYPE_RANDOM_COLOR:
            return colorRandom();
        case TYPE_RAINBOW_FULL_FIXED:
            return rainbowCompleteStatic(pos);
        case TYPE_RAINBOW_FULL_MOVING:
            return rainbowCompleteMoving(pos);
        case TYPE_RAINBOW_SINGLE_SHIFTING:
            return rainbowSingleColorShifting();
        case TYPE_RAINBOW_GRADUAL_MOVING:
            return rainbowGradualMoving(pos);   
    }
    return CRGB::Black;
}

void disableLeds() {
    for (int i = 0; i < NUM_LEDS; i++) {
        leds[i] = CRGB::Black;
    }
    FastLED.show();
}

// ###################################################################################################################################
// ###################################################################################################################################

void printNote(String type, byte channel, byte note, byte velocity) {
    PRINT("[");
    PRINT(type);
    PRINT(channel < 10 ? "]  #0" : "]  #");
    PRINT(channel);
    PRINT("  n=");
    PRINT(note);
    if (velocity > 0) {
      PRINT("  v=");
      PRINT(velocity);
    }
    PRINTLN("");
}

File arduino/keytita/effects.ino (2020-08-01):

/*
  Copyright (c) 2020 Thiago Lopes Rosa

 Licensed under the Apache License, Version 2.0 (the "License");
 you may not use this file except in compliance with the License.
 You may obtain a copy of the License at

 http://www.apache.org/licenses/LICENSE-2.0

 Unless required by applicable law or agreed to in writing, software
 distributed under the License is distributed on an "AS IS" BASIS,
 WITHOUT WARRANTIES OR CONDITIONS OF ANY KIND, either express or implied.
 See the License for the specific language governing permissions and
 limitations under the License.
 */

// static random color
CRGB colorRandom() {
    return pickRandomColor();
}

// complete static rainbow
CRGB rainbowCompleteStatic(unsigned int i) {
    return pickWheelColor((i * 256 / NUM_LEDS) & 255);
}

// complete moving rainbow colors
CRGB rainbowCompleteMoving(unsigned int i) {
    return pickWheelColor(((i * 256 / NUM_LEDS) + movingIndex) & 255);
}

// single color shifting rainbow
CRGB rainbowSingleColorShifting() {
    return pickWheelColor(movingIndex & 255);
}

// gradual moving rainbow colors
CRGB rainbowGradualMoving(unsigned int i) {
    return pickWheelColor((i + movingIndex) & 255);    
}

// ###################################################################
// ###################################################################

// get a random color
CRGB pickRandomColor() {
    switch (random(6)) {
    case 0:
        return CRGB(255, 0, 0);
    case 1:
        return CRGB(0, 255, 0);
    case 2:
        return CRGB(0, 0, 255);
    case 3:
        return CRGB(255, 255, 0);
    case 4:
        return CRGB(255, 0, 255);
    case 5:
        return CRGB(0, 255, 255);
    }
    return CRGB(255, 255, 255);
}

// pick a rainbow color
CRGB pickWheelColor(long pos) {
    pos = 255 - pos;
    if (pos < 85) {
        return CRGB(255 - pos * 3, 0, pos * 3);
    }
    if (pos < 170) {
        pos -= 85;
        return CRGB(0, pos * 3, 255 - pos * 3);
    }
    pos -= 170;
    return CRGB(pos * 3, 255 - pos * 3, 0);
}

// pick a note color
CRGB pickRainbowColor(byte index) {
    switch (index) {
    case 0:
        return CRGB(0xFF, 0, 0);
    case 1:
        return CRGB(0xFF, 0x80, 0);
    case 2:
        return CRGB(0xFF, 0xFF, 0);
    case 3:
        return CRGB(0, 0x80, 0);
    case 4:
        return CRGB(0, 0, 0xFF);
    case 5:
        return CRGB(0xFF, 0, 0xFF);
    case 6:
        return CRGB(0xFF, 0x69, 0xB4);        
    }
    return CRGB(255, 255, 255);
}

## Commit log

2020-05-25 CAD
    Piano keyboard created
    [Piano.scad, Piano.stl, Piano61.stl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]
2020-06-05 Arduino
    Bluetooth connection/setup and initial LED implementation
2020-06-09 Control
    Android application is now controlling the arduino, it is possible
    to change colors through the app
2020-06-10 Usability
    A lot of usability improvements on the android application, now
    it is easier to control the leds
2020-06-15 CAD
    First version of a KeyTita to be test printed
    [KeyTita.scad, KeyTita.stl, Piano.scad]
2020-06-18 CAD
    Second version, now separated in two parts
    [KeyTita.scad, KeyTita.stl, KeyTita_Exploded.stl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]
2020-06-23 CAD
    A lot of improvements, but still need some adjustments
    [KeyTita.scad]
2020-06-30 USB
    Added USB support to arduino and android app
    [KeyTita.scad]
2020-07-13 CAD
    All sections needed to be printed
    [KeyTita.scad, KeyTita.stl, KeyTita_Demo.stl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]
2020-07-21 CAD
    Final adjustments and print
    [KeyTita.scad, KeyTita_Printer_C2C3C4C5C6_Front_Padded.stl, KeyTita_Printer_C7C8_Front_Padded.stl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]
2020-07-27 CAD
    Box case added and printed
    [BoxCase_Base.scad, BoxCase_Button.scad, BoxCase_LidMid.scad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]
2020-08-01 Arduino
    Some adjustments and bug fixes
    [KeyTita.scad, KeyTita_DemoBox.stl, KeyTita_Printer_Case_Bottom.stl]
